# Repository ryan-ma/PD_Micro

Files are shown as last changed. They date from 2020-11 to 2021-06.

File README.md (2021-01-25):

# PD_Micro
ATMega32U4 Arduino board with USB-C PD Power Delivery and PPS

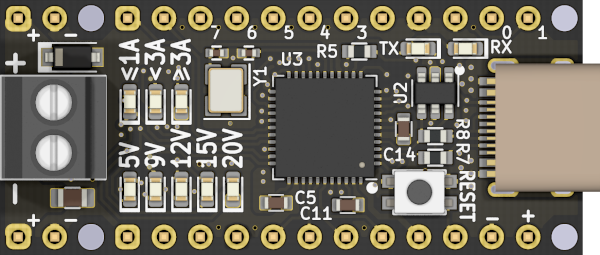
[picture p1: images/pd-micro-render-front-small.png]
Front Render


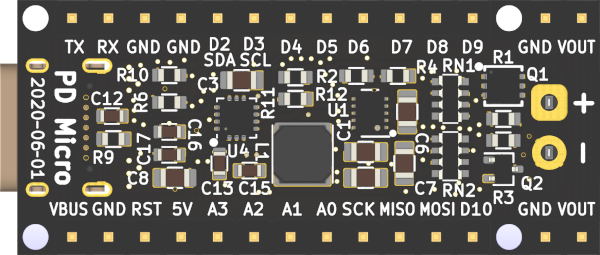
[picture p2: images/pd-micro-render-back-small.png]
Back Render


## Specs:
- ATmega32U4 running at 5 V and 16 MHz
- FUSB302 USB-C PHY (USB PD communication on CC pins)
- TPS62175 DC-DC for 5-20V input, 5V 500mA max output
- On-board 30V 10.4A P-channel MOSFET load switch
- 5 LEDs for power delivery voltage level
- 3 LEDs for power delivery current level
- 3.5 mm, 2 position terminal block for power output
- 1.6 x 0.7 inches (0.3 inches longer than pro micro)

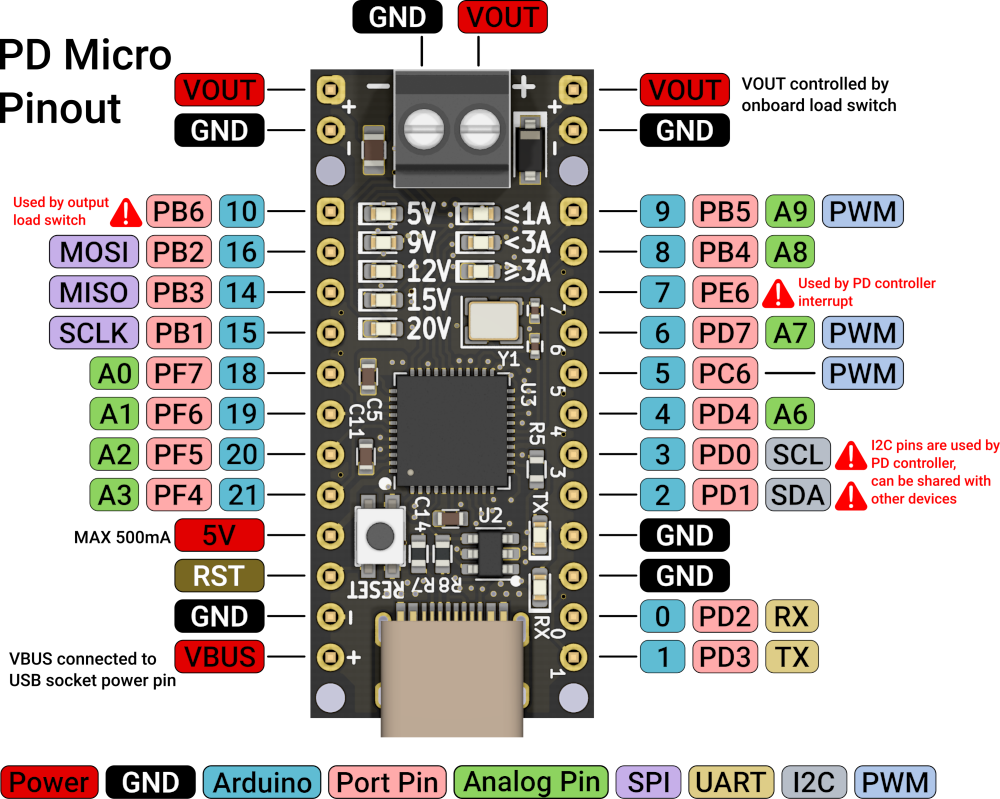
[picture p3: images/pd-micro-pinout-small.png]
Pin out


# Basic Usage

Open `PD_Micro.ino` with Arduino Sketch. Choose board `Arduino Leoardo`

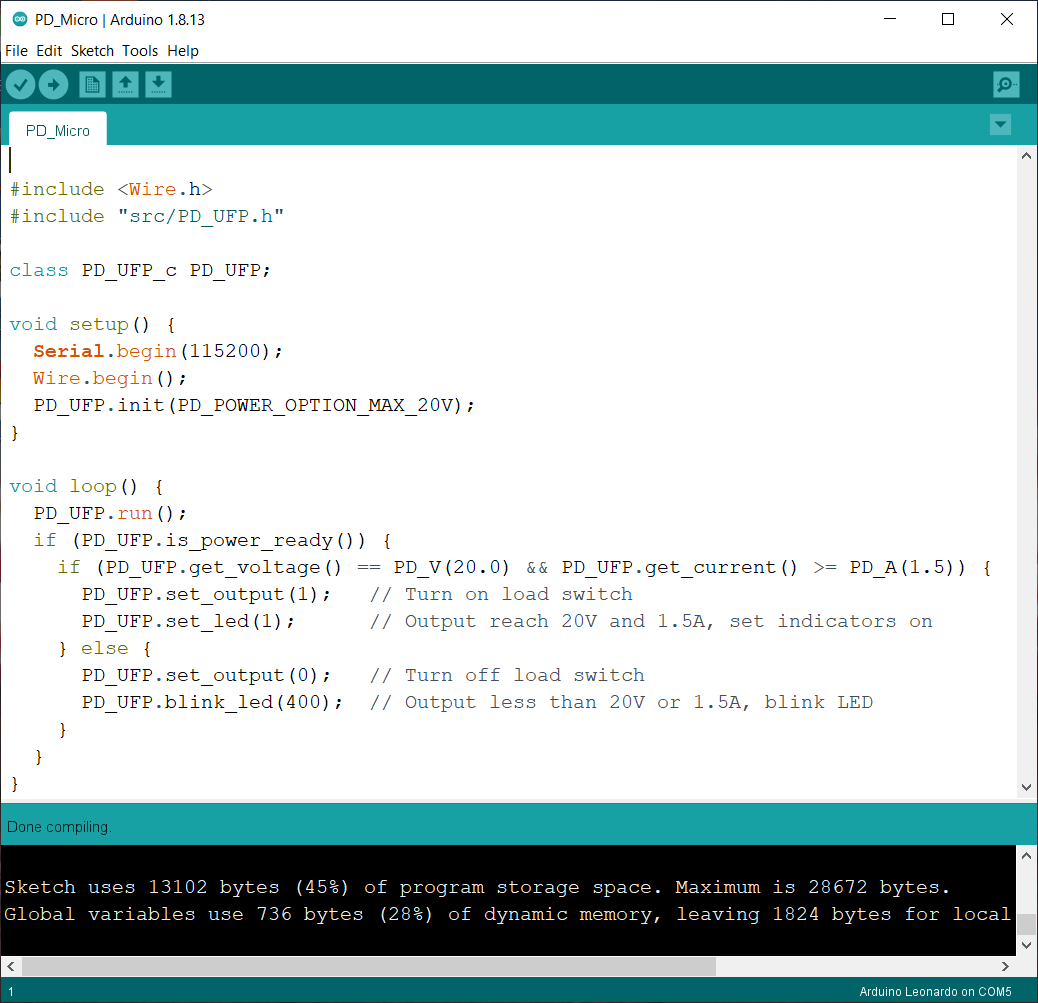
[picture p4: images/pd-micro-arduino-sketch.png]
arduino-sketch


## Set power option
Allocate a PD_UFP object
```
class PD_UFP_c PD_UFP;
```

Initialize it with one of the power options. That sets the maximum voltage/current. 
```
PD_UFP.init(PD_POWER_OPTION_MAX_20V);
```

```
enum PD_power_option_t {
    PD_POWER_OPTION_MAX_5V      = 0,
    PD_POWER_OPTION_MAX_9V      = 1,
    PD_POWER_OPTION_MAX_12V     = 2,
    PD_POWER_OPTION_MAX_15V     = 3,
    PD_POWER_OPTION_MAX_20V     = 4,
    PD_POWER_OPTION_MAX_VOLTAGE = 5,
    PD_POWER_OPTION_MAX_CURRENT = 6,
    PD_POWER_OPTION_MAX_POWER   = 7,
};
```

## Run USB PD state machine
Before USB PD negotiation had completed, `PD_UFP.run()` must be called in a short interval, less than 10ms, to ensure state machine response to negotiation message in time. Long response time may result in a power reset cycle initiated by USB PD hosts.

## Wait for USB PD negotiation completed
`PD_UFP.is_power_ready()` is set when
- PD negotiation completed, PD host sent a power ready message, or
- PD host not exist, CC pins voltage is checked and the power level determined.

The negotiation process typically takes less than a second.

## Examine the negotiated power value
Examine the negotiated power value. Turn on the load switch only when the power requirements are met. PD Micro itself does not have PD over current protection. Any excessive power usage may trigger USB PD host power protection, result in voltage dip and MCU reset. 

```
PD_UFP.run();
if (PD_UFP.get_voltage() == PD_V(20.0) && PD_UFP.get_current() >= PD_A(1.5)) {
  PD_UFP.set_output(1);   // Turn on load switch 
  PD_UFP.set_led(1);      // Output reach 20V and 1.5A, set indicators on
} else {
  PD_UFP.set_output(0);   // Turn off load switch
  PD_UFP.blink_led(400);  // Output less than 20V or 1.5A, blink LED
}
```
For Fix power option, `PD_UFP.get_voltage()` in 50 mV units and `PD_UFP.get_current()` in 10mA units. Use marco `PD_V` and `PD_A` to simplify conversion.

## Changing power option in run time
Power options can be changed any time after PD negotiation.
```
PD_UFP.set_power_option(PD_POWER_OPTION_MAX_20V);
```

`PD_UFP.is_ps_transition()` is set during power transition, clear when new power is ready. 
Power transition takes a maximum time of 550ms according to PD specifications. Depends on the power adapter, it is usually shorter.

# USB PD 3.0 PPS (Programmable Power Supply)
USB PD3.0 introduces a new PPS (Programmable Power Supply) mode. If PD source supports PPS, It allows devices to negotiate precise voltage range from 3.3V to 5.9/11/16/21 V with 20 mV step. PPS also supports a coarse current limit, with the value in 50 mA step.

The library provides another set of procedures to request PPS. If source PPS is not available or not qualified, it will fall back to use the regular PD power option.

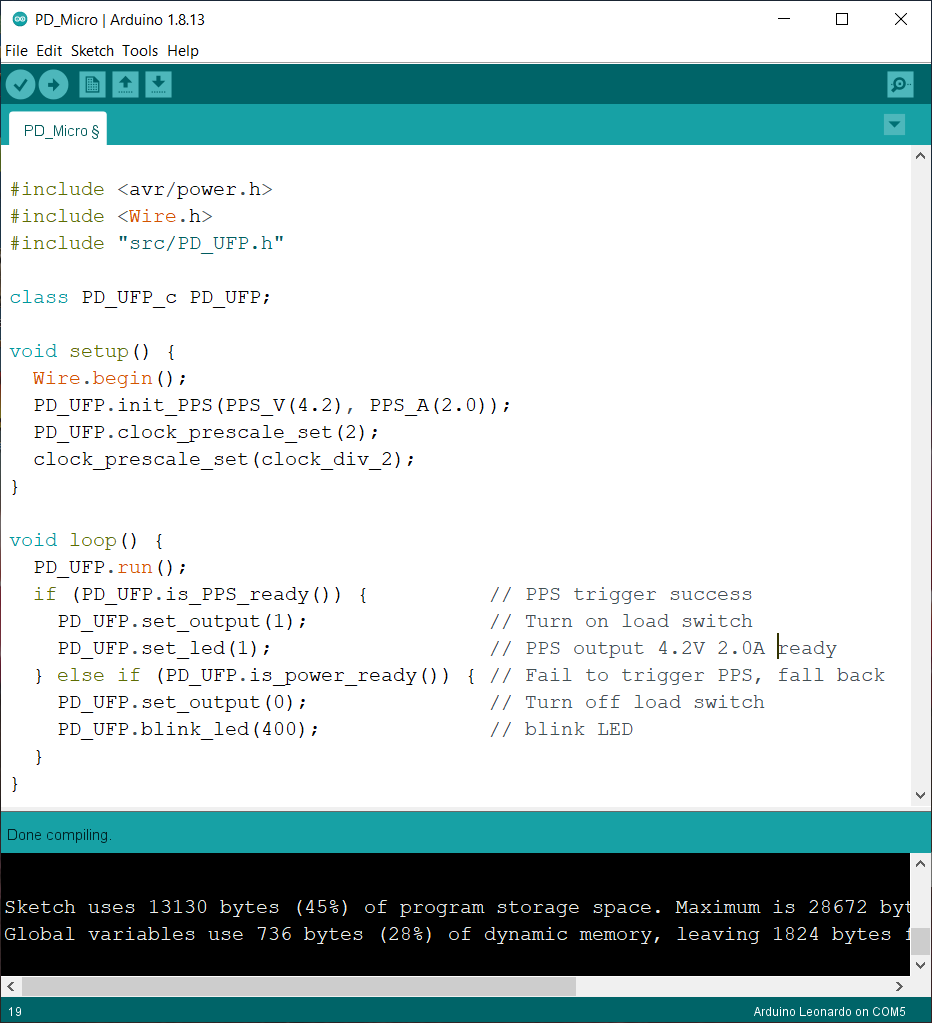
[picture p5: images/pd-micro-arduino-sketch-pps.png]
arduino-sketch


## Set voltage and current on startup
Instead of using `PD_UFP.init()`, use `PD_UFP.init_PPS()` to setup PPS voltage in 20 mV units and PPS current in 50 mA units. Use marco `PPS_V()` and `PPS_A()` to simplify conversion.
```
PD_UFP.init_PPS(PPS_V(4.2), PPS_A(2.0));
```
The default fall-back PD power option is 5V. It can be changed by an extra parameter.
```
PD_UFP.init_PPS(PPS_V(4.2), PPS_A(2.0), PD_POWER_OPTION_MAX_9V);
```

PD Micro use ATMega32U4 with safe operation 8MHz @ <4.5V. To request PPS below 4.5V, use `clock_prescale_set(clock_div_2)` to slow down the working frequency, and use `PD_UFP.clock_prescale_set(2)` to prescale the library internal clock.
```
PD_UFP.clock_prescale_set(2);
clock_prescale_set(clock_div_2);
```

## Wait for USB PD PPS trigger completed
Once PD negotiation is completed,
- If PPS is available and qualified, `PD_UFP.is_PPS_ready()` is set. 
- If PPS is not available or qualified, `PD_UFP.is_power_ready()` is set.

If PPS is successfully triggered, the output voltage and current will be the exact value provided in the startup. It is not required to examine negotiated voltage and current.
```
PD_UFP.run();
if (PD_UFP.is_PPS_ready()) {          // PPS trigger success
  PD_UFP.set_output(1);               // Turn on load switch 
  PD_UFP.set_led(1);                  // PPS output 4.2V 2.0A ready
} else if (PD_UFP.is_power_ready()) { // Fail to trigger PPS, fall back
  PD_UFP.set_output(0);               // Turn off load switch
  PD_UFP.blink_led(400);              // blink LED
}
```
For PPS, `PD_UFP.get_voltage()` in 20 mV units and `PD_UFP.get_current()` in 50 mA units. Use marco `PPS_V()` and `PPS_A()` to simplify conversion.

## Changing PPS voltage and current in run time
PPS settings can be changed any time after PPS ready. Similar to `PD_UFP.init_PPS()`, set voltage in 20 mV units and current in 50 mA units. Use Marco `PPS_V()` and `PPS_A()` to simplify conversion.
```
PD_UFP.set_PPS(PPS_V(3.3), PPS_A(2.0));
```

`PD_UFP.is_ps_transition()` is set during power transition, clear when new power is ready. 
Power transition takes a maximum time of 550 ms according to specification. It is usually less than 50ms in PPS mode. 

By calling `PD_UFP.set_PPS()`, the library re-evaluates all PPS source capabilities to find the best fit. If it fails to find one, it returns false, no power request, and power transition will happen.

To exit PPS mode, call `PD_UFP.set_power_option()` to clear PPS setting and fall back to regular power option mode.

# LED Indicators
There are 5 LEDs for voltage and 3 LEDs for current on PD_Micro, multiplexed by 6 internal IO pins. These are managed by the PD_UFP library. 

The library turn on voltage LED according to the following table

| Voltage Range | LED | 
| --- | --- |
| >= 3.3V && < 9V | 5V | 
| >= 9V && < 12V | 9V | 
| >= 12V && < 15V | 12V | 
| >= 15V && < 20V | 15V | 
| >= 20 | 20V | 

# Debugging
The library can log library status, source capabilities, protocol packets, with timestamps in the millisecond step to the serial port.

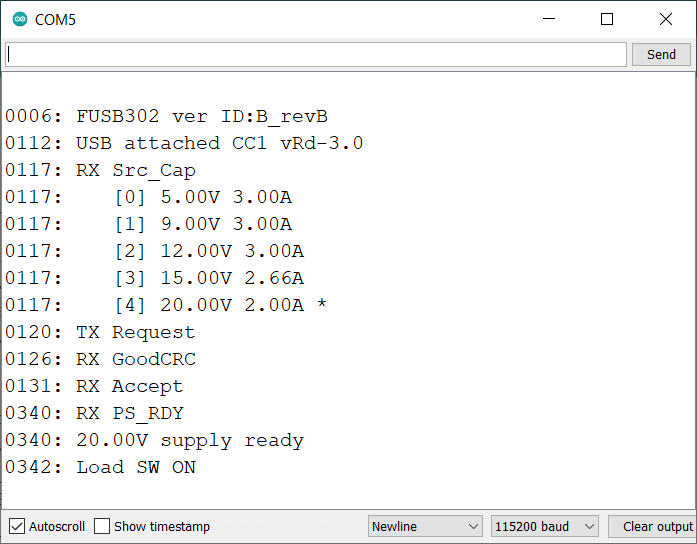
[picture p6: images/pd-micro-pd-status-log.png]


To use it, allocate PD_UFP object with derived class `PD_UFP_log_c`
```
class PD_UFP_log_c PD_UFP;
```
initialize hardware serial1 in setup.
```
void setup() {
  Serial1.begin(115200);
  ...
```
call `PD_UFP.print_status(Serial1)` inside `loop()`.
```
void loop() {
  PD_UFP.run();
  PD_UFP.print_status(Serial1);
  ...
```
Connect Pin 1 (PD3 / UART TX) and GND to external USB to UART to read serial messages.

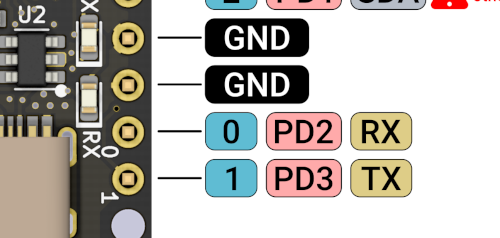
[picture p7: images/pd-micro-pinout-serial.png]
serial


PD Micro can be converted to serial passthrough mode and use it as USB to UART. I included these Arduino sketch examples in <a href="/examples">examples</a> folder.

## Debug raw packets
The library provides two log levels. Initialize PD_UFP with extra parameter `PD_LOG_LEVEL_VERBOSE` to output raw packets
```
class PD_UFP_log_c PD_UFP(PD_LOG_LEVEL_VERBOSE);
```
```
enum pd_log_level_t {
    PD_LOG_LEVEL_INFO,
    PD_LOG_LEVEL_VERBOSE
};
```
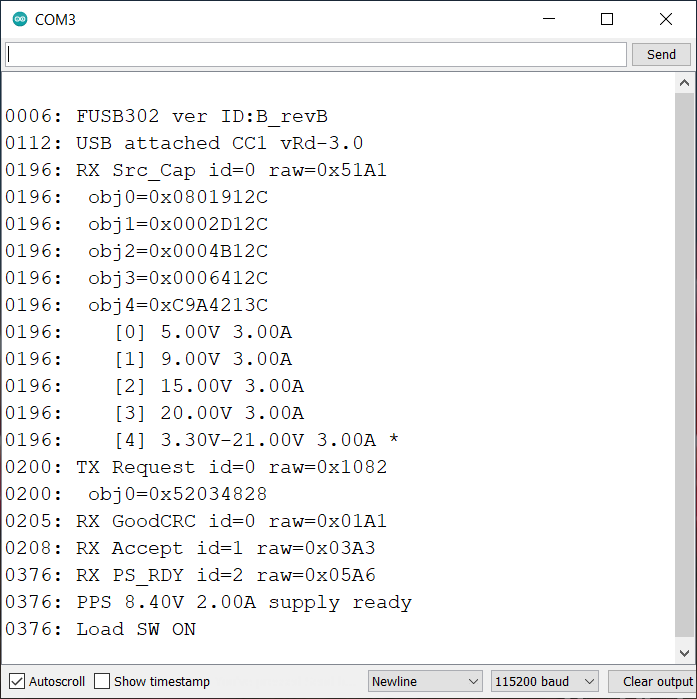
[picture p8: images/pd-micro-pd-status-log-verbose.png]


# Bootloader
PD Micro uses `Caterina-promicro16.hex` bootloader provided by Sparkfun. Program it by `avrdude` and set the corresponding `efuse`.
```
avrdude -p m32u4 -P usb -c avrispmkii -U flash:w:Caterina-promicro16.hex -U efuse:w:0xcb:m -U hfuse:w:0xd8:m -U lfuse:w:0xff:m
```

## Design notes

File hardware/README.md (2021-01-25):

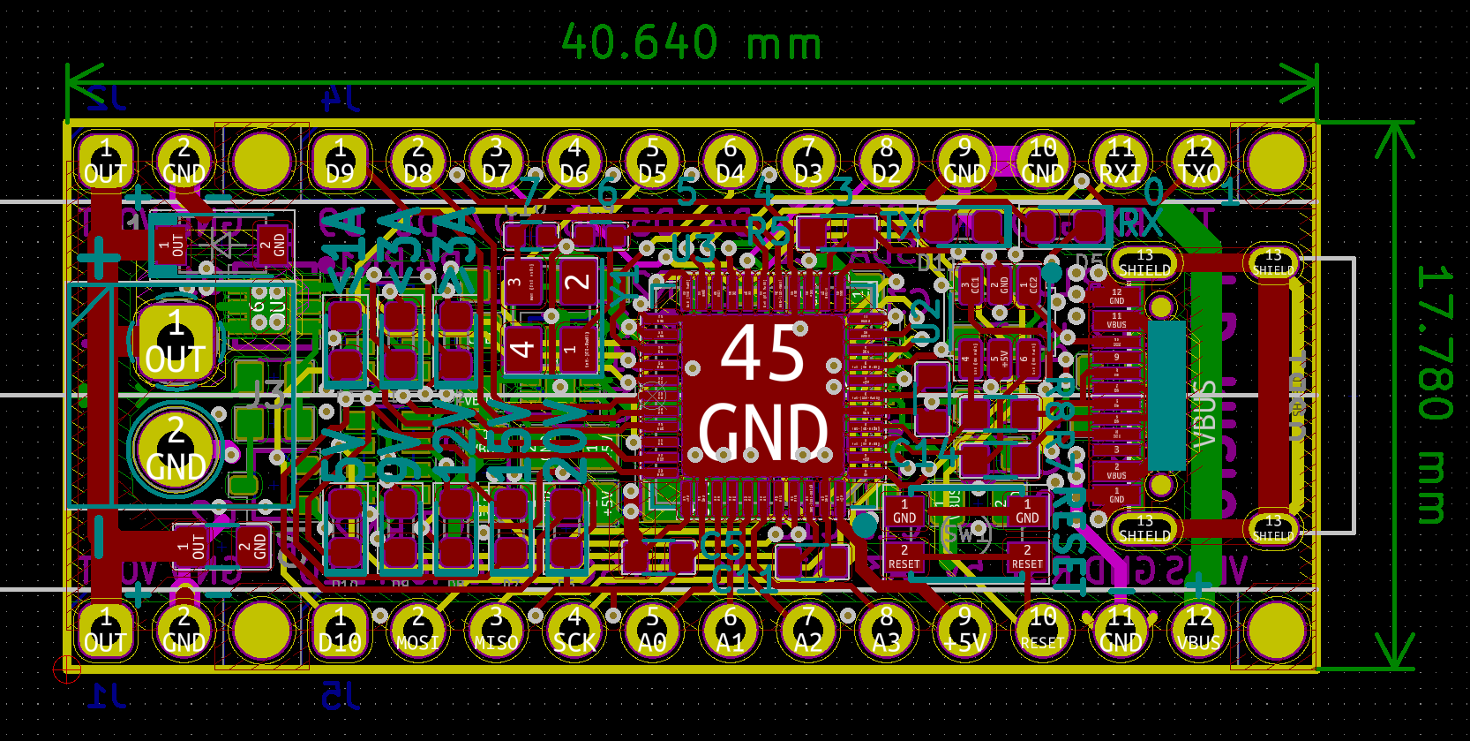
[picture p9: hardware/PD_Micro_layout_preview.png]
Layout preview


# Schematic diagram
https://github.com/ryan-ma/PD_Micro/blob/master/hardware/PD_Micro_schematic-2020-06-01.pdf

# Interactive BOM
https://htmlpreview.github.io/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

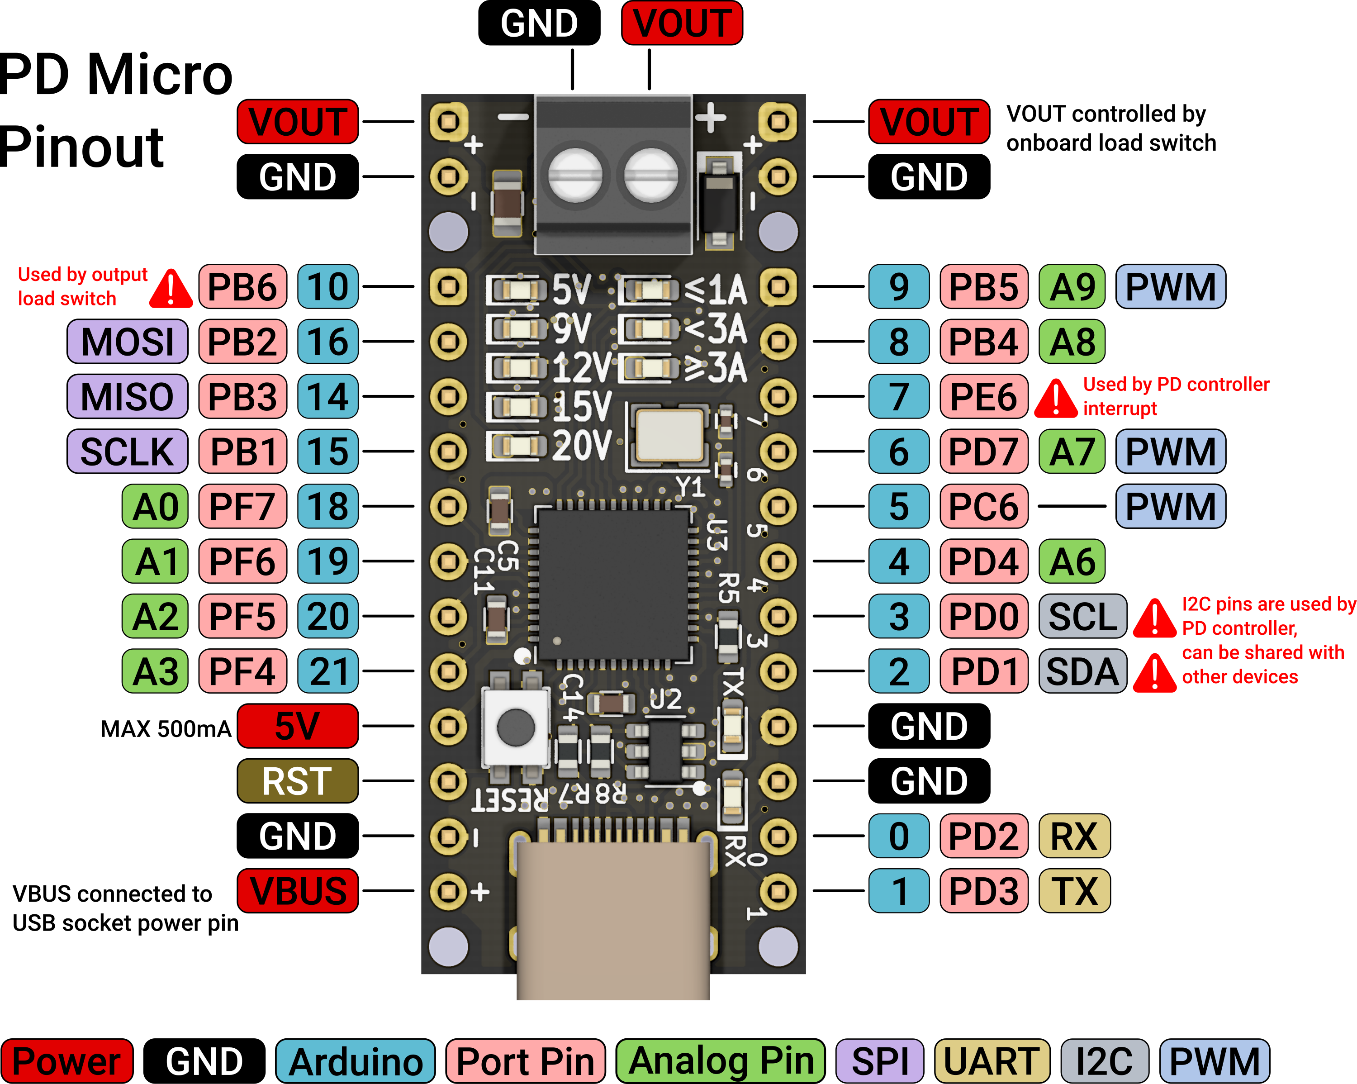
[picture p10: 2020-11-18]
images/pd-micro-pinout.png

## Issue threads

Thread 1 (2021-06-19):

Current limit not being enforced in PPS mode

nsluhrs, 2021-06-19:
Hello,

I was doing some testing with my shiny new PD Micro and it doesn't seem to be respecting the current limiting.
I can pull 380mA despite setting the current limit to 200mA.
Just as a sanity check here's the init line I'm using. Everything else is the same as the pps example file.
`  PD_UFP.init_PPS(PPS_V(9.2), PPS_A(0.2));`
The load is 25 Ohm at dc and 66mH (not that inductance should matter in this case.

I honestly kind of doubt this is a problem with the PD Micro, I suspect it may be an issue with the [USB PSU I'm using](https://www.amazon.com/gp/product/B08FCCN6CP/), but any debugging advice would be nice.

Best,
Nik

ryan-ma, 2021-06-19:
Hi Nik,

The current limit in PPS is quite coarse. The PD spec only requires the PD power supplies to provide accuracy of 150mA when souring more than 1A, or +/-5% when souring more than 3A.

USB_PD_R3_0 V2.0 20190829.pdf - page 246 - 7.1.4.4 Programmable Power Supply Current Limit
```
......
The PPS Operating Current regulation accuracy during Current Limit is
defined as iPpsCLNew. The minimum programmable Current Limit level is iPpsCLMin.
......
```

USB_PD_R3_0 V2.0 20190829.pdf - page 309 - 7.4.1 Source Electrical Parameters
```
......
iPpsCLMin (Minimum Current Limit setting)
- Minimum: 1A
iPpsCLNew (Current Limit accuracy)
- 1A ≤ Operating Current ≤ 3A : +/-150mA
- Operating current > 3A : +/- 5%
......
```

Closed 2021-08-24.

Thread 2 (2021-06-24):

Get list of possible voltages/current limits

kaythe, 2021-06-24:
It could be very useful to get all the possible voltages and current limits the power supply supports. The debug output contains such a list, but a method to get this list would be far more useful.

danricho, 2021-07-04:
This would be great as I don't know how we can toggle between available options without an external controller.

kaythe, 2021-07-05:
I played around with it and added a method to get the information based on the way it already uses for the debug log. I'll make a pull request once I polished it up a bit.

danricho, 2021-07-05:
Awesome! Looking forward to seeing it!

danricho, 2021-07-18:
@kaythe, do you think you could share a draft of your improvement? I haven't been able to do the same :(

kaythe, 2021-07-19:
> @kaythe, do you think you could share a draft of your improvement? I haven't been able to do the same :(

I haven't had the time to work on it unfortunately, but I'll see if I can get you a rough version today

kaythe, 2021-07-20:
@danricho it took a bit longer than expected but you should now be able to see it here: https://github.com/kaythe/PD_Micro/commit/a686b230e8572daadeb7dc137b0377f7306190fc

I want to add some error handling before I create a pull request though.

danricho, 2021-07-20:
Looks great so far. And even a display output added!

I'm planning to do similar to create a "bench power supply" using either the voltage levels available or PPS if the source can do it.

I will have a tinker when I have some time at my bench.

Cheers!

gyboy, 2021-07-21:
hey,guys,it looks like we all think same things,I have made one  OLED current measure kit using INA219 and STM32 reffernced "USB Tester OLED Backpack" on github,recently I want to add the PD function so that this kit can generate any voltage and limit current while draw the scope of voltage, the PCB is done and I am debugging the software,but I have met problem with transmit the code to C while the oringinal code is C ,the software build passed while the target voltage don't change,I an still trying to find the problems.

ryan-ma, 2021-07-27:
Hi, guys, sorry for this late reply. I did write some code on getting the list of possible voltage and current. But I haven't had time to try and verify so far.

PD micro code is designed to be small to fit into low cost embedded platform. It should be easy to just edit the PD_UFP.cpp to fit your own needs. If you need to port to other platforms, just follow PD_UFP.cpp to implement these handlers.
- PD_Protocol events handler
- FUSB302 events handler
- timer handler
- interrupt handler

I will work on porting it to Atmel SAMD51 with a new dev board with LCD this year

kaythe, 2021-07-28:
> PD micro code is designed to be small to fit into low cost embedded platform.

Yeah that's why I made the method as short as possible. It's a bit annoying to use this way but it should take up a minimum amount of time and memory. I already had to split the display initialization up into several small parts so I could use it without blocking the PD loop ^^"

If you could integrate a nicer method to access the possible voltages and currents that'd be great, otherwise my solution does everything *I*needed.

danricho, 2021-07-28:
I've had success with your method also @kaythe.

My last step is to add listing PPS mode as a selectable mode aside from the set voltages available. I'm still yet to look how I will do that, how to test for it and to get the ranges available.

Ueberspannung, 2023-08-18:
There is a simple way of getting the available PDOs. Just initialize to 5V Fix provile. When done all PDOs ar stored in the protocol structure

I'm ausing a wrappe class derived from PD_UFP_c

`
bool 	PD_PPS_c::get_PDO_info(uint8_t PDO, PD_power_info_t * power_info)	// gets advertised voltage in mV
{ 	//	get_PDO_info 														   current in mA, power in 0,01W
	memset(power_info,0,sizeof(PD_power_info_t));
	if (PD_protocol_get_power_info(&protocol,PDO,power_info))
	{	// recalculate units
		power_info->min_v*=50;	//  50 mV units => [min_v]= 1 mV
		power_info->max_v*=50;	//  50 mV units => [max_v]= 1 mV
		power_info->max_i*=10;	//  10 mA units => [max_i]= 1 mA
		power_info->max_p*=25;	// 250 mW units => [max_p]=10 mW
		return true;
	}	// recalculate units
	else
		return false;
}	//	get_PDO_info											
`

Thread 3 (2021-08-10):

avrdude: butterfly_recv(): programmer is not responding

jenesaisdiq, 2021-08-10:
Hey, I'm just getting around to using one of the PD Micros, and I'm getting this error when I try to flash it. Using Arduino IDE 1.8.13 on MacOS 11.4.

I'm also seeing the onboard LEDs blinking- 5V and <3A are both blinking. Does this indicate that the bootloader needs to be reflashed?

ryan-ma, 2021-08-13:
Hi, I just tried with my M1 MacBook Air, MacOS 11.51, and yes, it fails.
It seems with the board connected to MacBook, It cannot enter bootloader mode by all means.
Typically, double click the reset button will enter bootloader mode, and <=1A LED will start breathing. Can try to connect to the type-C power adapter and do the double click to verify.

Blinking 5V <3A means the power source only supports up to 5V <3A, which does not meet the target voltage/current.

I remember I did success program on the PD micro with MacBook. I will investigate what is going on with the new MacOS.

jenesaisdiq, 2021-08-13:
Thank you! I switched over to a Win10 desktop and it's working fine, so not a problem with this PD Micro

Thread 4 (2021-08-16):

PPS above 11V exits after 5 seconds of triggering

sakura-ushio, 2021-08-16:
My charger supports 5-20V 5A PPS, but it will exit PPS 5 seconds after triggering PPS above 11v. Why？

ryan-ma, 2021-08-24:
Hi, I just realize a bug that may related to your problem.
The power_data_obj[] array in PD_protocol_t should be size of 7 instead of 6, which will cause power negotiation fail or even crash if number of PDO is more than 6.
I pushed the fix. See if this can solve your issue.

sakura-ushio, 2021-08-25:
Now the PPS above 11V works perfectly.

Closed 2021-08-25.

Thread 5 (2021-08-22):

Add a diode between VBus and the USB-C connector?

EternityForest, 2021-08-22:
Hey! I love this board, but one thing that would really enable a lot of use cases is an additional diode that prevented backflow from VBus to the USB port, and a second diode that allowed current flow from the pin header back to the voltage regulator.

With that, we would have a choice of a few different operating modes with a battery connected to the IO header:

* Q1 turned off,  PD requesting a voltage above the battery voltage, running directly from USB

* Q1 on, PD requesting constant current, battery is charging

* No USB power, battery is powering the voltage regulator

As far as I can tell, battery charging is one of the most exciting uses for this, and it would be amazing to use the onboard voltage regulator when on battery power.

ryan-ma, 2021-08-24:
Thanks for your suggestion. I noticed this problem after the board was completed and mass produced.
I am working on the next generation PD trigger. Stay tune in CrowdSupply.

EternityForest, 2021-09-10:
Great to hear! Sounds like this device will truly be a world first in the next rev!

doug-gilbert, 2021-11-12:
Many designs have back to back PFETs, joined at their Sources with a common Gate drive as a Vbus switch (rather than a single PFET). Would this stop the backflow you are concerned about?

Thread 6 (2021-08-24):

Voltage present after load switch is set to off

Benjin454, 2021-08-24:
Is the load switch suppose to cut all power from vout? When PD_UFP.set_output is set to zero I'm still getting 5v. Is there a way to completely cut off voltage to vout?

ryan-ma, 2021-08-24:
Yes, the load switch is supposed to cut all power from VBUS to VOUT. Can you check if the Q1 MOSFET gate was not pull down and  Q2 Transistor Base is ON?

Benjin454, 2021-08-24:
Thanks you for the response. I actually have two pd micros. Just tried the other one and it works as expected. The soldering iron potentially was too hot on the first one when I was soldering on the screw terminal. In turn possibly damaging the load P-Channel MOSFET? Ill look into it more later. Thanks again.

faultylee, 2022-01-04:
> The soldering iron potentially was too hot on the first one when I was soldering on the screw terminal.
@Benjin454 It's likely not the temperature. Most soldering iron leaks, and since most MOSFET's gate behave like a capacitor and the leaking current might built up voltages higher than expected for the Gate causing it to breakdown, which then keeping it "turn-on" permanently. The solution to this is to ground the soldering iron tip, see https://electronics.stackexchange.com/questions/11583/grounding-a-soldering-iron.

Another possibility is ESD (electro-static discharge). If you live in a dry climate or work inside a cold and dry air-conditioned room with carpet floor, this could easily happen as well, when our finger carries the high voltage static and discharged through the MOSTFET's Gate.

Closed 2022-01-04.

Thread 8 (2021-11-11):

Bootloader

gcormier, 2021-11-11:
I'm losing my mind with this Caterina bootloader. Having a TON of issues on Windows *and* Linux. Has anyone else had issues?

Button toggling has inconsistent behavior.. serial port continuously disconnecting... I've reflashed the bootloader with no real change in behaviour.

I guess I could just outright wipe it and stick to my AVR programmer? Seems like a pity but really not sure what to do.

gcormier, 2021-11-11:
I switched to Windows for now. So I have the Arduino Blink sketch flashed for fun. This causes the 1A led to blink on/off every second.

When I compile and upload from PlatformIO.

```
Advanced Memory Usage is available via "PlatformIO Home > Project Inspect"
RAM:   [===       ]  32.0% (used 819 bytes from 2560 bytes)
Flash: [=====     ]  48.5% (used 13918 bytes from 28672 bytes)
Configuring upload protocol...
AVAILABLE: avr109
CURRENT: upload_protocol = avr109
Looking for upload port...
Auto-detected: COM3
Forcing reset using 1200bps open/close on port COM3
Waiting for the new upload port...
Error: Couldn't find a board on the selected port. Check that you have the correct port selected. If it is correct, try pressing the board's reset button after initiating the upload.
*** [upload] Explicit exit, status 1
============================================================================================================================================== [FAILED] Took 6.56 seconds ==============================================================================================================================================
The terminal process "C:\Users\Greg\.platformio\penv\Scripts\platformio.exe 'run', '--target', 'upload'" terminated with exit code: 1.

Terminal will be reused by tasks, press any key to close it.
```

And now, the RX/TX won't stop blinking. Clicking reset will briefly turn off the leds while depressed, then they resume blinking. Holding reset for any amount of time will turn off the LEDs, then they resume blinking. Unplugging the PD Micro is the only way to return to normal blink.

Closed 2023-06-22.

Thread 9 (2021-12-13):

Doesn't recongnize when charging cable is unplugged

phippstech, 2021-12-13:
I have the code on a custom board of mine (the design is based off the kicad design as well) and everything works for the most part except when I unplugged the device, the LED I have for when the

phippstech, 2021-12-13:
`void loop()
{
  //analogWrite(LPWM, 255);
  int voltage = analogRead(VBATT);
  PD_UFP.run();
  if (PD_UFP.is_power_ready())
  {
    if (PD_UFP.get_voltage() == PD_V(20.0) && PD_UFP.get_current() >= PD_A(1.5))
    {
       digitalWrite(LED1,HIGH);
    }
	  else
	  {
		  digitalWrite(LED1,LOW);
	  }
  }
}`

phippstech, 2021-12-15:
So I printed the
`PD_UFP.get_voltage() > PD_V(14.0)`

and it remains at the same value when the USBC cable is disconnected. Is that suppose to happen or is suppose to go back to zero?

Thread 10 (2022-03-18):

PPS defaults to 5V after working correctly for 60 seconds

awc105, 2022-03-18:
Hi, I have been making use of this library for a project I am working on. I have successfully run it on: nRF52832, nRF52840, and SAMD51, all cortex-M4. Using adafruit feather bootloaders for all boards. I am using a small FUSB302 breakout board from Tindie.
The PD2.0 functionality of this library works great, using 4 different adapters I was able to enable all PDOs on each adapter!

The adapters I am using are:
Apple 87W Charger, PD2.0 only
Wotobeus 130W Charger, PD3.0 capable of 3.3-21V @ 5A using PPS
Samsung 25W Charger, PD3.0 capable of 3.3-21V @ 1A using PPS

The cables I am using are:
Samsung 100W Marked Cable
Cable Matters 100W Marked Cable (USB-IF certified)

What chargers/cables did you use when testing?

I am also able to use PPS to set voltage and current, this works well and I have even load tested the current limiting, however on both PPS capable adapters I have, the **PPS voltage will drop out after 60-80 seconds on average and default to PD2.0**. Unplugging the cable from the charger and plugging it back in will fix the problem for another 60-80 seconds.

Do you have any suggestions or ideas as to why this is happening?
To me it seems to be perhaps a timing issue?
Are there any parameters that I should be specifically looking at?

I have PD_UFP.run() in the main loop (using arduino) with a 1ms delay to service the state machine, I also have another version of the code where PD_UFP.run() is in a timer callback that runs at 1ms as well. Both give me the same issue.

One last small issue is that setting the PPS voltage to 21V will still yield an output of 20V on both PPS chargers even though they are capable of 21V

Thank you very much for the help!

-Andrew

awc105, 2022-03-31:
Perhaps a clue. I spent some time playing around with the timings for pps request and was able to get it to run stable for an hour, but after that it would still fault and resort to PD2.0. I then tried it using an atmega328p and it ran fine without a problem. What could be the difference?

jarrod89, 2024-10-15:
Your issue is due to the way the ARM32 compiler handles unsigned arithmetic and overflows vs the AVR compiler, I fixed this in a PR for a forked repo here, the same changes should fix this repo https://github.com/kcl93/fusb302_arduino/pull/4

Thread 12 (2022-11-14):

Support for PD 3.1 48V

3dberg, 2022-11-14:
Thank you for the great work! This project is awesome and I will watch it.

**Are you planning to integrate support for PD3.1 up to 48V in the near future?**

Ueberspannung, 2023-08-18:
The FUSB302 is only ratet for VBUS<21V (abs. max. 28V)

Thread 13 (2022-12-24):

Anywhere to buy these currently?

ryancdotorg, 2022-12-24:
CrowdSupply won't even let me place a preorder. :-/

awesome-manuel, 2023-01-13:
https://eu.mouser.com/ProductDetail/392-CS-PDMICRO-01

ryancdotorg, 2023-01-13:
Any clarity on when (or even if) that might be fufilled?

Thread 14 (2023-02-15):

Wifi enabled with API?

Felixrising, 2023-02-15:
Whilst the ATMega32U4 based MCU provides a nice well understood Arduino compatible platform, the idea of a ESP8266 or ESP32 based version with wifi and configuration webpage/API for app based control seems like a really useful option for PD based board.

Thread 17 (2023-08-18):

Does not work with power bank

Ueberspannung, 2023-08-18:
I tried an Anker Nexode 100W -> no problems
I tried an INIU BI-B5 20Ah powerbank. after 10sec without load the Powerbank cycles the power and does not establish PD mode again.
I tested 9V Fix and 9V PPS mode. Using an 20Ohms Resistor as load, the powerbank stays alive.
I tested one of the ebay/amazon ZY12PDN boards with the powerbank (without load) -> Works as intended

I attached 4 log files in verbose mode.

[INIU_9V_Fix_load_20R.txt](https://github.com/ryan-ma/PD_Micro/files/12379525/INIU_9V_Fix_load_20R.txt)
[INIU_9V_Fix_no_load.txt](https://github.com/ryan-ma/PD_Micro/files/12379526/INIU_9V_Fix_no_load.txt)
[INIU_9V_PPS_load_20R.txt](https://github.com/ryan-ma/PD_Micro/files/12379528/INIU_9V_PPS_load_20R.txt)
[INIU_9V_PPS_no_load.txt](https://github.com/ryan-ma/PD_Micro/files/12379529/INIU_9V_PPS_no_load.txt)

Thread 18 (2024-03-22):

Multiple voltage output?

digimbyte, 2024-03-22:
Looking for a system that can output 3v and 12v together from usb-C
I saw a picture that had a 3v and 20v lights enabled suggesting that its outputting both? but I maybe wrong and it instead outputs 23v on the connectors.

any suggestions on how to extract 3v would be nice as I plan to mod my retro console and it needs `12v@3A` and `3v@1A`
I don't want to power drain the board but im confident I can use the 3v from the chip and have it configured to the 12v I need.

suggestions and feedback welcome

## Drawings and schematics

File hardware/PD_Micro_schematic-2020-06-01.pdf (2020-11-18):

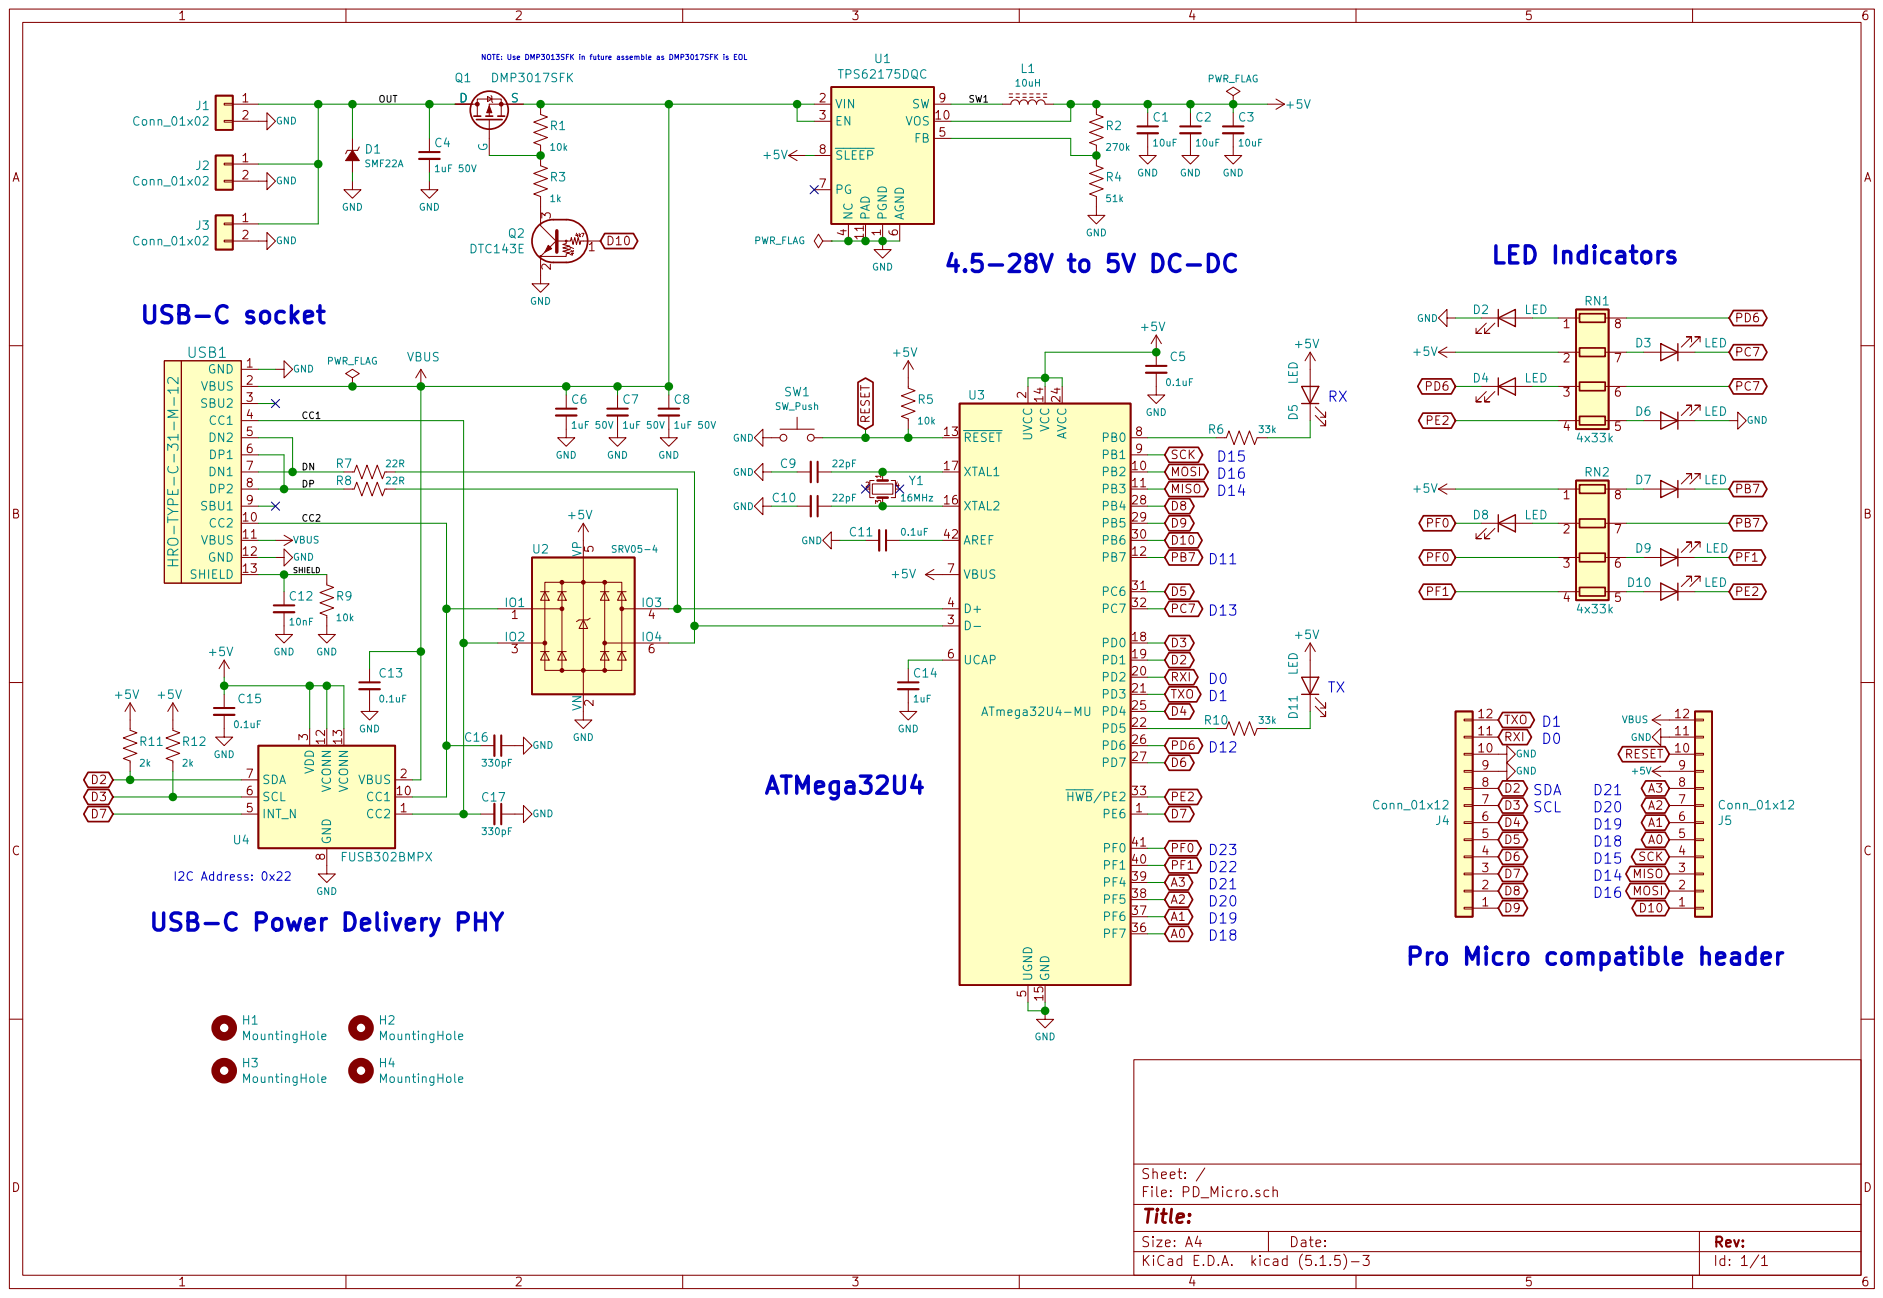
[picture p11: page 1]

1 VOS 10 PAD 11 VIN 2 EN 3 NC

2 PD2 20 PD3 21 PD5 22 AVCC 24 PD4 25 PD6 26 PD7 27 PB4 28 PB5 29 D- 3 PB6 30 PC6 31 PC7 32 HWB/PE2 33 PF7 36 PF6 37 PF5 38 PF4 39 D+ 4 PF1 40 PF0 41 AREF 42 UGND

USB-C Power Delivery PHY

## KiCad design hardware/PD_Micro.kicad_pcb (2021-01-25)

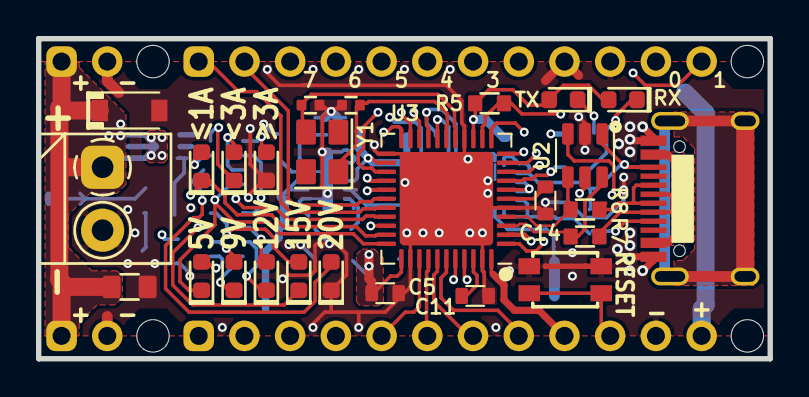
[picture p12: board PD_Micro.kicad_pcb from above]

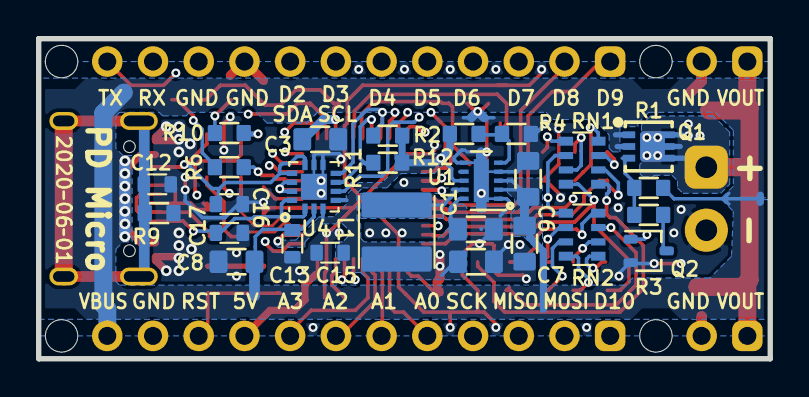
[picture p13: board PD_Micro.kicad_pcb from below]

Board: 4 copper layers, 40.6 x 17.8 mm, 61 parts (31 on the bottom side), 56 nets.

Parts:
C1, C2, C3: 10uF; C_0805
C4, C6, C7, C8: 1uF 50V; C_0805
C5, C11, C13, C15: 0.1uF; C_0603
C9, C10: 22pF; C_0402
C12: 10nF; C_0603
C14: 1uF; C_0603
C16, C17: 330pF; C_0603
D1: SMF22A; D_SOD-123
D2, D3, D4, D5, D6, D7, D8, D9, D10, D11: LED; LED_0603_1608Metric
H1, H2, H3, H4: MountingHole; D1_8_PAD
J1, J2: Conn_01x02; PinHeader_1x02_P2.54mm_Vertical
J3: Conn_01x02; TerminalBlock_3.5mm_2P
J4, J5: Conn_01x12; PinHeader_1x12_P2.54mm_Vertical
L1: 10uH; L_4012
Q1: DMP3017SFK; DFN-2523-6
Q2: DTC143E; SOT-323_SC-70
R1, R5, R9: 10k; R_0603
R2: 270k; R_0603
R3: 1k; R_0603
R4: 51k; R_0603
R6, R10: 33k; R_0603
R7, R8: 22R; R_0603
R11, R12: 2k; R_0603
RN1, RN2: 4x33k; R_Array_Convex_4x0603
SW1: SW_Push; SW_SPST_3.5x3mm
U1: TPS62175DQC; WSON-10-1EP_2x3mm_P0.5mm_EP0.84x2.4mm
U2: SRV05-4; SOT-23-6
U3: ATmega32U4-MU; QFN-44-1EP_7x7mm_P0.5mm_EP5.2x5.2mm
U4: FUSB302BMPX; WQFN-14-1EP_2.5x2.5mm_P0.5mm_EP1.45x1.45mm
USB1: HRO-TYPE-C-31-M-12
Y1: 16MHz; Crystal_SMD_3225-4Pin_3.2x2.5mm

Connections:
+5V: C1.1, C2.1, C3.1, C5.1, C15.1, D5.2, D11.2, J5.9, L1.2, R2.1, R5.1, R11.1, R12.1, RN1.2, RN2.1, U1.8, U1.10, U2.5, U3.2, U3.7, U3.14, U3.24, U3.34, U3.44, U4.3, U4.4, U4.12, U4.13
/CC1: C17.2, U2.3, U4.1, U4.14, USB1.4
/CC2: C16.2, U2.1, U4.10, U4.11, USB1.10
/DN: R7.2, USB1.5, USB1.7
/DP: R8.2, USB1.6, USB1.8
/OUT: C4.1, D1.1, J1.1, J2.1, J3.1, Q1.4, Q1.5, Q1.6
/SHIELD: C12.1, R9.1, USB1.13
/SW1: L1.1, U1.9
A0: J5.5, U3.36
A1: J5.6, U3.37
A2: J5.7, U3.38
A3: J5.8, U3.39
D2: J4.8, R11.2, U3.19, U4.7
D3: J4.7, R12.2, U3.18, U4.6
D4: J4.6, U3.25
D5: J4.5, U3.31
D6: J4.4, U3.27
D7: J4.3, U3.1, U4.5
D8: J4.2, U3.28
D9: J4.1, U3.29
D10: J5.1, Q2.1, U3.30
GND: C1.2, C2.2, C3.2, C4.2, C5.2, C6.2, C7.2, C8.2, C9.2, C10.2, C11.2, C12.2, C13.2, C14.2, C15.2, C16.1, C17.1, D1.2, D2.1, D6.1, J1.2, J2.2, J3.2, J4.9, J4.10, J5.11, Q2.2, R4.2, R9.2, SW1.1, U1.1, U1.4, U1.6, U1.11, U2.2, U3.5, U3.15, U3.23, U3.35, U3.43, U3.45, U4.8, U4.9, U4.15, USB1.1, USB1.12
MISO: J5.3, U3.11
MOSI: J5.2, U3.10
unnamed: C9.1, U3.17, Y1.1
unnamed: C10.1, U3.16, Y1.3
unnamed: C11.1, U3.42
unnamed: C14.1, U3.6
unnamed: D2.2, RN1.1
unnamed: D3.2, RN1.7
unnamed: D4.2, RN1.3
unnamed: D5.1, R6.1
unnamed: D6.2, RN1.5
unnamed: D7.2, RN2.8
unnamed: D8.2, RN2.2
unnamed: D9.2, RN2.6
unnamed: D10.2, RN2.5
unnamed: D11.1, R10.1
unnamed: Q1.3, R1.2, R3.1
unnamed: Q2.3, R3.2
unnamed: R2.2, R4.1, U1.5
unnamed: R6.2, U3.8
unnamed: R7.1, U2.6, U3.3
unnamed: R8.1, U2.4, U3.4
unnamed: R10.2, U3.22
PB7: D7.1, RN2.7, U3.12
PC7: D3.1, RN1.6, U3.32
PD6: D4.1, RN1.8, U3.26
PE2: D10.1, RN1.4, U3.33
PF0: D8.1, RN2.3, U3.41
PF1: D9.1, RN2.4, U3.40
RESET: J5.10, R5.2, SW1.2, U3.13
RXI: J4.11, U3.20
SCK: J5.4, U3.9
TXO: J4.12, U3.21
VBUS: C6.1, C7.1, C8.1, C13.1, J5.12, Q1.1, Q1.2, R1.1, U1.2, U1.3, U4.2, USB1.2, USB1.11

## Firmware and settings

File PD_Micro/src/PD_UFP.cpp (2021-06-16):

/**
 * PD_UFP.h
 *
 *  Updated on: Jan 28, 2021
 *      Author: Ryan Ma
 *
 * Minimalist USB PD Ardunio Library for PD Micro board
 * Only support UFP(device) sink only functionality
 * Requires FUSB302_UFP.h, PD_UFP_Protocol.h and Standard Arduino Library
 *
 * Support PD3.0 PPS
 * 
 */
 
#include <stdint.h>
#include <string.h>

#include "PD_UFP.h"

#define t_PD_POLLING            100
#define t_TypeCSinkWaitCap      350
#define t_RequestToPSReady      580     // combine t_SenderResponse and t_PSTransition
#define t_PPSRequest            5000    // must less than 10000 (10s)

#define PIN_OUTPUT_ENABLE       10
#define PIN_FUSB302_INT         7

#define PIN_LED_CURRENT_1       13
#define PIN_LED_CURRENT_2       12
#define PIN_LED_VOLTAGE_1       // PE2 not support by ardunio library, manipulate register directly
#define PIN_LED_VOLTAGE_2       22
#define PIN_LED_VOLTAGE_3       23
#define PIN_LED_VOLTAGE_4       11

enum {
    STATUS_LOG_MSG_TX,
    STATUS_LOG_MSG_RX,
    STATUS_LOG_DEV,
    STATUS_LOG_CC,
    STATUS_LOG_SRC_CAP,
    STATUS_LOG_POWER_READY,
    STATUS_LOG_POWER_PPS_STARTUP,
    STATUS_LOG_POWER_REJECT,
    STATUS_LOG_LOAD_SW_ON,
    STATUS_LOG_LOAD_SW_OFF,
};


///////////////////////////////////////////////////////////////////////////////////////////////////
// PD_UFP_core_c
///////////////////////////////////////////////////////////////////////////////////////////////////
PD_UFP_core_c::PD_UFP_core_c():
    ready_voltage(0),
    ready_current(0),
    PPS_voltage_next(0),
    PPS_current_next(0),
    status_initialized(0),
    status_src_cap_received(0),
    status_power(STATUS_POWER_NA),
    time_polling(0),
    time_wait_src_cap(0),
    time_wait_ps_rdy(0),
    time_PPS_request(0),
    get_src_cap_retry_count(0),
    wait_src_cap(0),
    wait_ps_rdy(0),
    send_request(0)
{
    memset(&FUSB302, 0, sizeof(FUSB302_dev_t));
    memset(&protocol, 0, sizeof(PD_protocol_t));
}

void PD_UFP_core_c::init(enum PD_power_option_t power_option)
{
    init_PPS(0, 0, power_option);
}

void PD_UFP_core_c::init_PPS(uint16_t PPS_voltage, uint8_t PPS_current, enum PD_power_option_t power_option)
{
    // Initialize FUSB302
    pinMode(PIN_FUSB302_INT, INPUT_PULLUP); // Set FUSB302 int pin input ant pull up
    FUSB302.i2c_address = 0x22;
    FUSB302.i2c_read = FUSB302_i2c_read;
    FUSB302.i2c_write = FUSB302_i2c_write;
    FUSB302.delay_ms = FUSB302_delay_ms;
    if (FUSB302_init(&FUSB302) == FUSB302_SUCCESS && FUSB302_get_ID(&FUSB302, 0, 0) == FUSB302_SUCCESS) {
        status_initialized = 1;
    }

    // Two stage startup for PPS Voltge < 5V
    if (PPS_voltage && PPS_voltage < PPS_V(5.0)) {
        PPS_voltage_next = PPS_voltage;
        PPS_current_next = PPS_current;
        PPS_voltage = PPS_V(5.0);
    }

    // Initialize PD protocol engine
    PD_protocol_init(&protocol);
    PD_protocol_set_power_option(&protocol, power_option);
    PD_protocol_set_PPS(&protocol, PPS_voltage, PPS_current, false);

    status_log_event(STATUS_LOG_DEV);
}

void PD_UFP_core_c::run(void)
{
    if (timer() || digitalRead(PIN_FUSB302_INT) == 0) {
        FUSB302_event_t FUSB302_events = 0;
        for (uint8_t i = 0; i < 3 && FUSB302_alert(&FUSB302, &FUSB302_events) != FUSB302_SUCCESS; i++) {}
        if (FUSB302_events) {
            handle_FUSB302_event(FUSB302_events);
        }
    }
}

bool PD_UFP_core_c::set_PPS(uint16_t PPS_voltage, uint8_t PPS_current)
{
    if (status_power == STATUS_POWER_PPS && PD_protocol_set_PPS(&protocol, PPS_voltage, PPS_current, true)) {
        send_request = 1;
        return true;
    }
    return false;
}

void PD_UFP_core_c::set_power_option(enum PD_power_option_t power_option)
{
    if (PD_protocol_set_power_option(&protocol, power_option)) {
        send_request = 1;
    }
}

void PD_UFP_core_c::clock_prescale_set(uint8_t prescaler)
{
    if (prescaler) {
        clock_prescaler = prescaler;
    }
}

FUSB302_ret_t PD_UFP_core_c::FUSB302_i2c_read(uint8_t dev_addr, uint8_t reg_addr, uint8_t *data, uint8_t count)
{
    Wire.beginTransmission(dev_addr);
    Wire.write(reg_addr);
    Wire.endTransmission();
    Wire.requestFrom(dev_addr, count);
    while (Wire.available() && count > 0) {
        *data++ = Wire.read();
        count--;
    }
    return count == 0 ? FUSB302_SUCCESS : FUSB302_ERR_READ_DEVICE;
}

FUSB302_ret_t PD_UFP_core_c::FUSB302_i2c_write(uint8_t dev_addr, uint8_t reg_addr, uint8_t *data, uint8_t count)
{
    Wire.beginTransmission(dev_addr);
    Wire.write(reg_addr);
    while (count > 0) {
        Wire.write(*data++);
        count--;
    }
    Wire.endTransmission();
    return FUSB302_SUCCESS;
}

FUSB302_ret_t PD_UFP_core_c::FUSB302_delay_ms(uint32_t t)
{
    delay(t / clock_prescaler);
    return FUSB302_SUCCESS;
}

void PD_UFP_core_c::handle_protocol_event(PD_protocol_event_t events)
{    
    if (events & PD_PROTOCOL_EVENT_SRC_CAP) {
        wait_src_cap = 0;
        get_src_cap_retry_count = 0;
        wait_ps_rdy = 1;
        time_wait_ps_rdy = clock_ms();
        status_log_event(STATUS_LOG_SRC_CAP);
    }
    if (events & PD_PROTOCOL_EVENT_REJECT) {
        if (wait_ps_rdy) {
            wait_ps_rdy = 0;
            status_log_event(STATUS_LOG_POWER_REJECT);
        }
    }    
    if (events & PD_PROTOCOL_EVENT_PS_RDY) {
        PD_power_info_t p;
        uint8_t i, selected_power = PD_protocol_get_selected_power(&protocol);
        PD_protocol_get_power_info(&protocol, selected_power, &p);
        wait_ps_rdy = 0;
        if (p.type == PD_PDO_TYPE_AUGMENTED_PDO) {
            // PPS mode
            FUSB302_set_vbus_sense(&FUSB302, 0);
            if (PPS_voltage_next) {
                // Two stage startup for PPS voltage < 5V
                PD_protocol_set_PPS(&protocol, PPS_voltage_next, PPS_current_next, false);
                PPS_voltage_next = 0;
                send_request = 1;
                status_log_event(STATUS_LOG_POWER_PPS_STARTUP);
            } else {
                time_PPS_request = clock_ms();
                status_power_ready(STATUS_POWER_PPS, 
                    PD_protocol_get_PPS_voltage(&protocol), PD_protocol_get_PPS_current(&protocol));
                status_log_event(STATUS_LOG_POWER_READY);
            }
        } else {
            FUSB302_set_vbus_sense(&FUSB302, 1);
            status_power_ready(STATUS_POWER_TYP, p.max_v, p.max_i);
            status_log_event(STATUS_LOG_POWER_READY);
        }
    }
}
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

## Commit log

2021-01-25 Add Kicad design files
    [PD_Micro.kicad_pcb, PD_Micro.sch]
2021-01-28 Bug fix and add example
    [PD_Micro_template_PPS_4.2V_2A_logging.ino, PD_UFP.cpp]
2021-06-16 Fix PPS current parsing. Add power type string in logging
    [PD_UFP.cpp]
2021-08-24 Fix power negotiation fail if number of PDO is more than 6
    [PD_UFP_Protocol.h]
